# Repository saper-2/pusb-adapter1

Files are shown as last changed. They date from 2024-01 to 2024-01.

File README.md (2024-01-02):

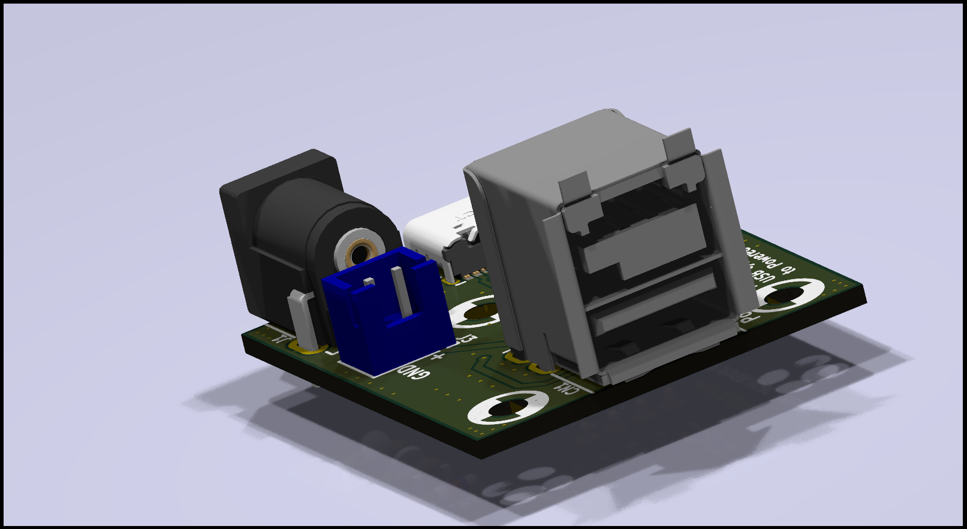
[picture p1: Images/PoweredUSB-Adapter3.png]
Render3D-3

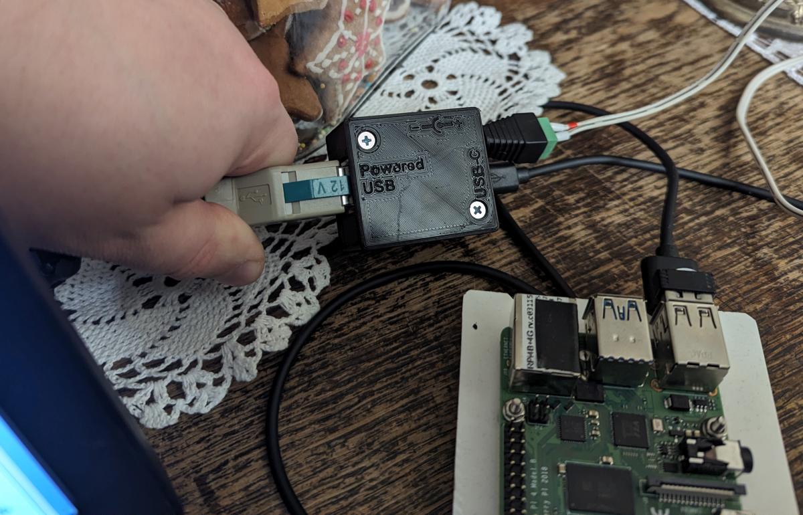
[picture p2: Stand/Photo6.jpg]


# PoweredUSB Adapter board
This repo contains design files for PoweredUSB adapter to USB-C (USB 1.1/2.0 mode) or pinheader with additional power connector (barrel jack socket 5,5x2,1(2,5)mm or JST 2.5mm).

In zip file `PoweredUSB-Adapter-PCB-Fab-Files.zip` are packed gerbers for pcb fab house (this is compressed `out` folder).

In schematic (PDF too) you'll find  part numbers.

In folder `Images` you'll find some 3d renders and pcb dimensions.

## Adapter chassis

In `Chassis` folder you'll find a STLs for adapter box, check readme inside for assembly details.

## Stand
I have designed desk stand for those displays, you can find STL to print on 3D printer (FDM) in `Stand` (and some photos).

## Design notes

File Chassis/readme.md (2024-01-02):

# Chassis for Adapter module

Use 2 nuts M3 + 2 screws M3x25 (DIN 965 / ISO 7046)

Either solder USB-C 16pin connector or solder usb cable to 1x4 goldpin, and cut 2 traces in marked locations (so USB signals won't go back to empty USB-C footprint)

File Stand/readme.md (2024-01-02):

This is v.1.1 stand for Fujitsu 7" LCD Display KD02902-6132 

- Print with support from bed.
- 4 walls, infill 50%

I used PET-G because I had loaded already, but PLA, ABS, other materials will work fine too.

Changelog:
- v1.0 - initial version
- v1.1 - longer front legs, a bit longer central hole so display is about 8-10mm higher, decreased central diameter so lcd will sit more stable (won't be rotating itself).

Stand model also on Thingiverse: https://www.thingiverse.com/thing:6413668

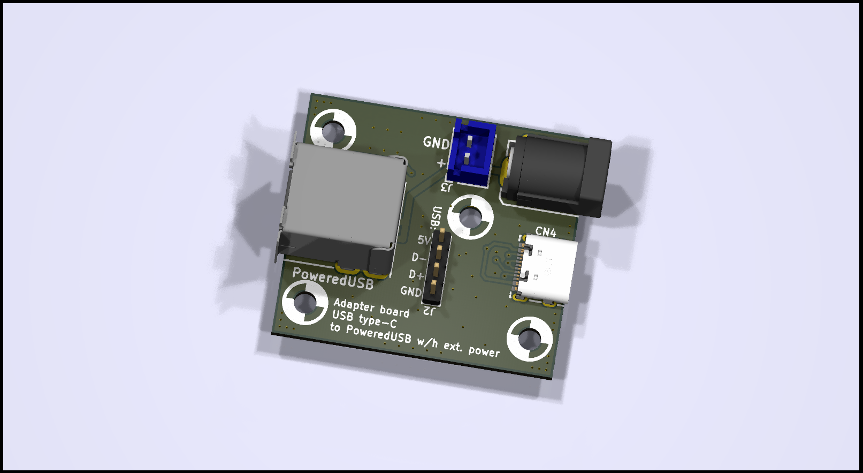
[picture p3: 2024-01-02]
Images/PoweredUSB-Adapter1.png

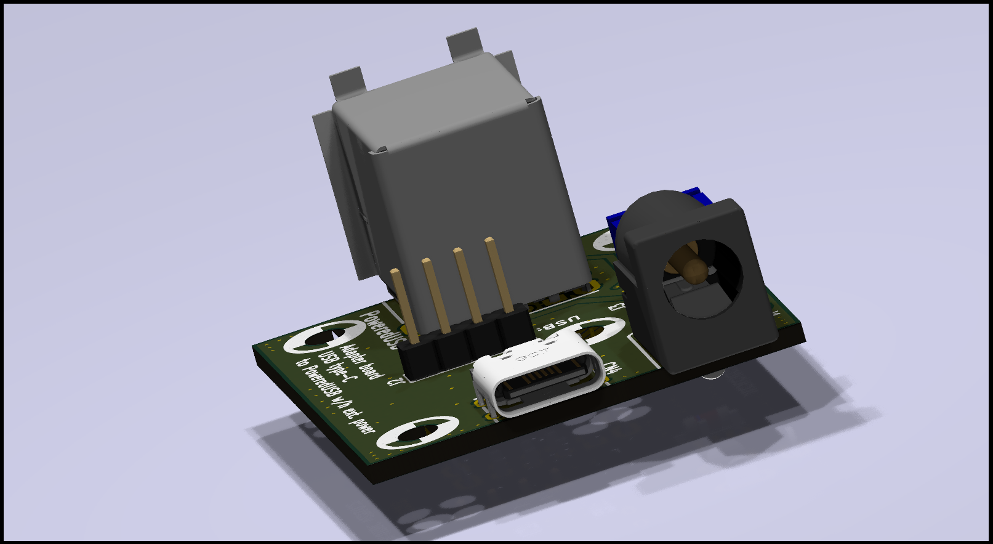
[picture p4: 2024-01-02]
Images/PoweredUSB-Adapter4.png

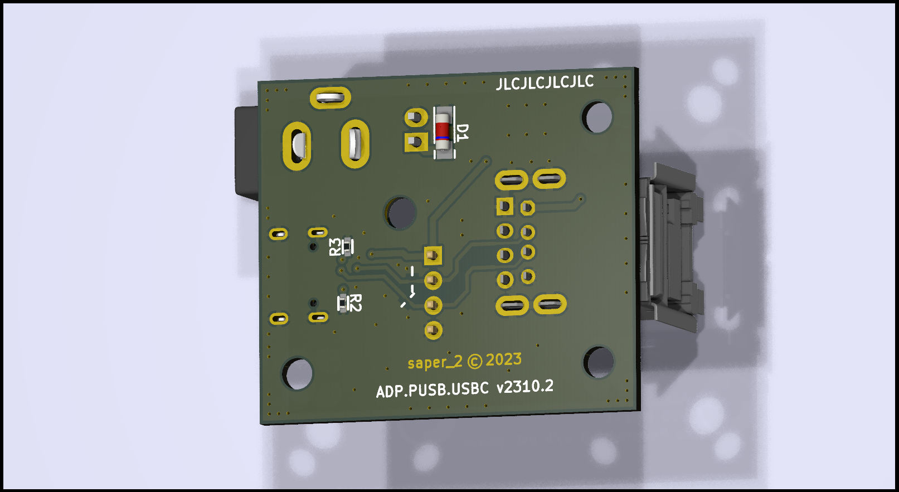
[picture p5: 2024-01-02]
Images/PoweredUSB-Adapter2.png

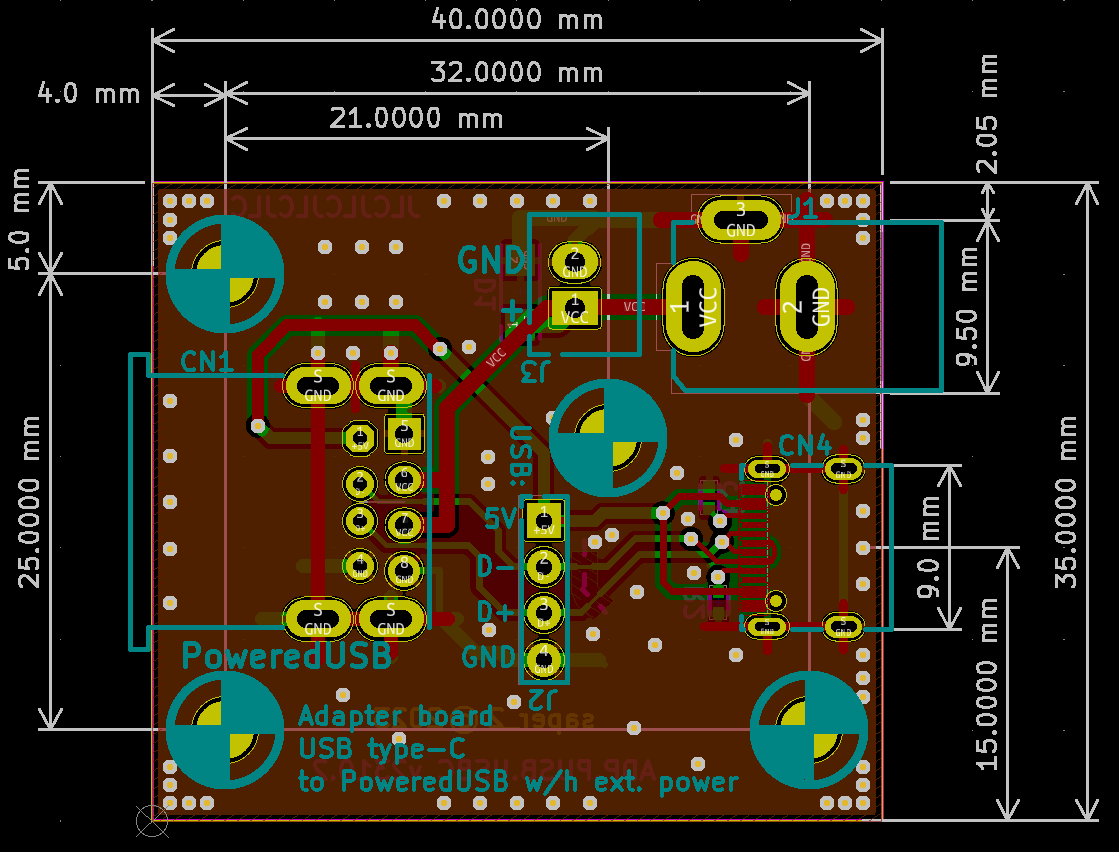
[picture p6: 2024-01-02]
Images/PoweredUSB-Adapter-PCB-Dims.png

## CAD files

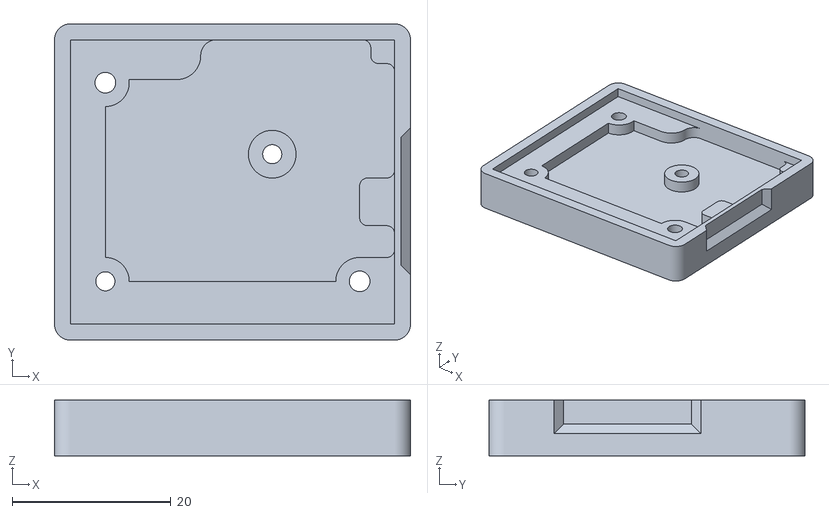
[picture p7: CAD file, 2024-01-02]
Chassis/PoweredUSB-Chassis-Bot(USBC).stl
44.8 x 39.8 x 7.00

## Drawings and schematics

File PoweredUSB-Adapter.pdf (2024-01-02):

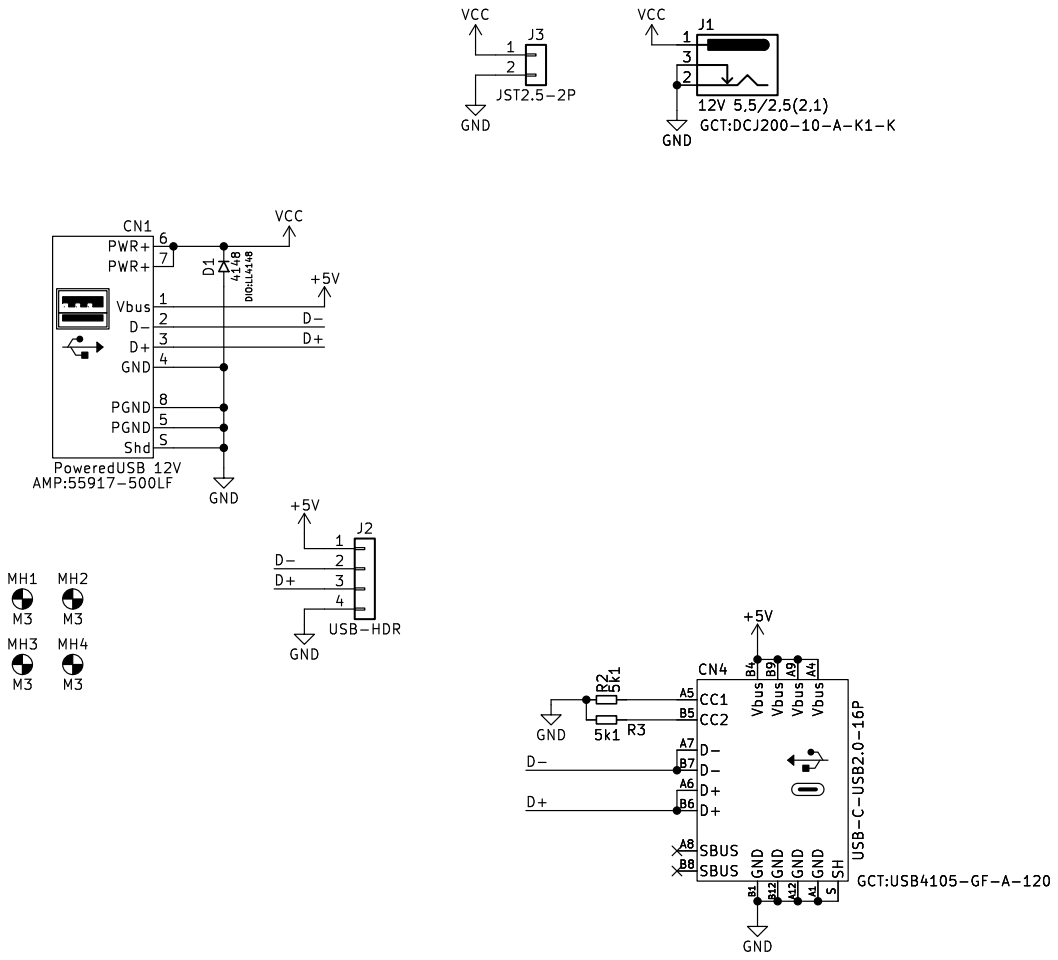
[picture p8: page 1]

S CN4 USB-C-USB2.0-16P GCT:USB4105-GF-A-120 GND

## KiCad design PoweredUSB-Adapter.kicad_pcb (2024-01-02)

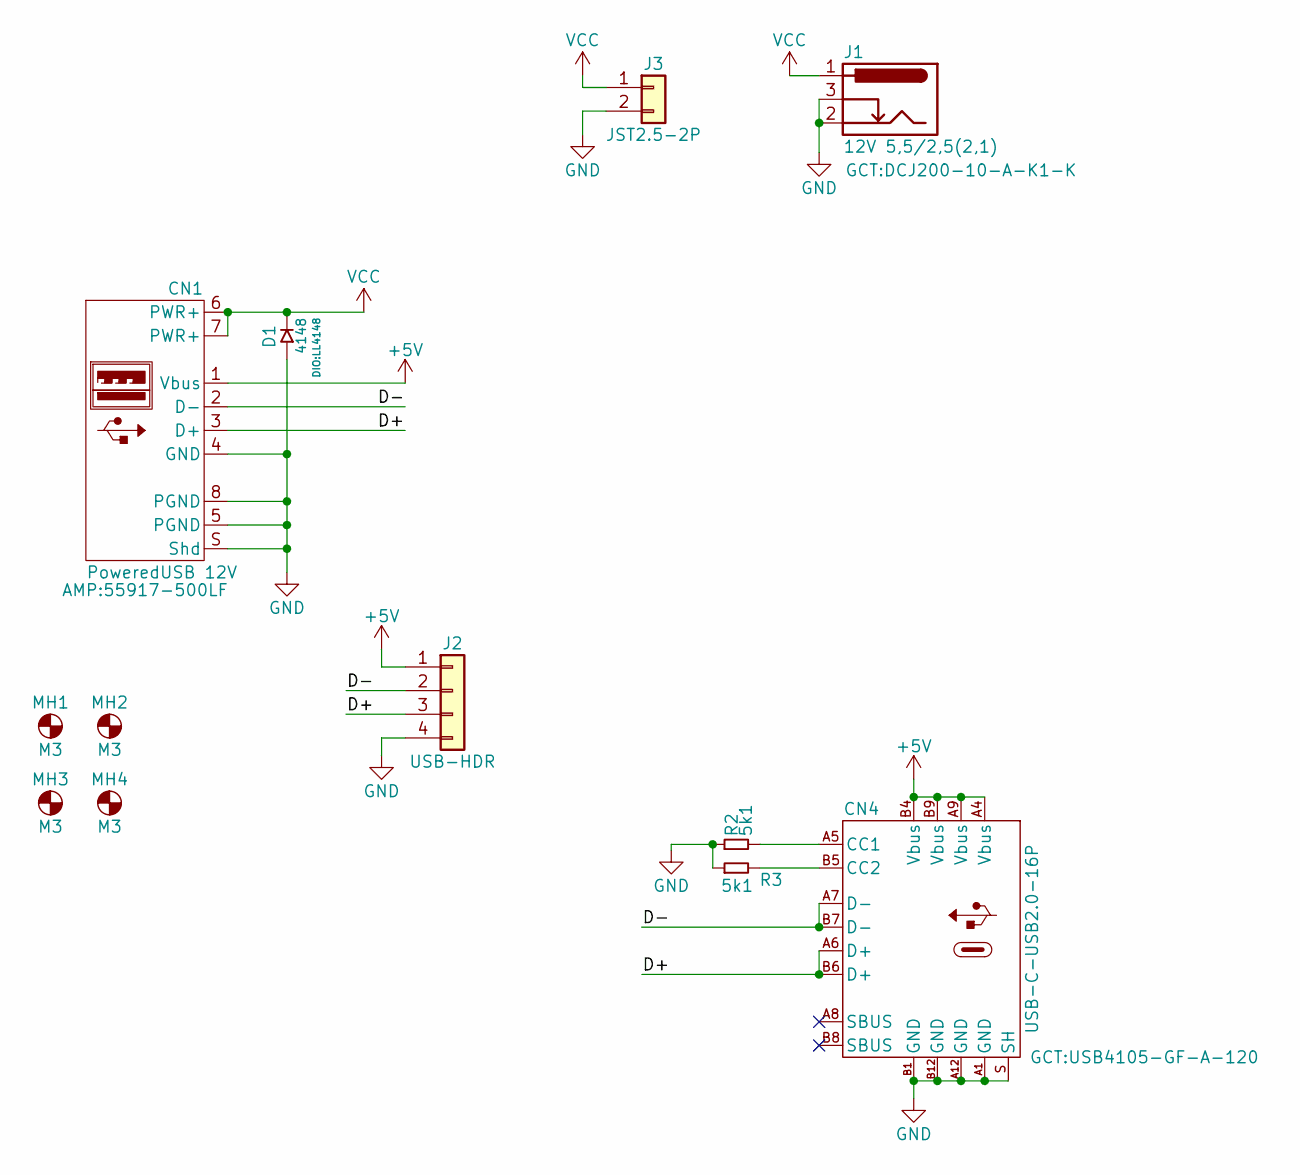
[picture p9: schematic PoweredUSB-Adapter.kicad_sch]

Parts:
CN1: PoweredUSB 12V; AMP_55917-500LF
CN4: USB-C-USB2.0-16P; USBC-F-USB2-16P
D1: 4148; D_MiniMELF_HS
J1: 12V 5,5/2,5(2,1); DC_POWER
J2: USB-HDR; HDR1X04_V
J3: JST2.5-2P; WG04S-2.5-02P-V
MH1, MH2, MH3, MH4: M3; MHOLE-3.2MM
R2, R3: 5k1; R_0402_HS2

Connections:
+5V: CN1.1 (Vbus), CN4.A4 (Vbus), CN4.A9 (Vbus), CN4.B4 (Vbus), CN4.B9 (Vbus), J2.1
/D+: CN1.3 (D+), CN4.A6 (D+), CN4.B6 (D+), J2.3
/D-: CN1.2 (D-), CN4.A7 (D-), CN4.B7 (D-), J2.2
GND: CN1.4 (GND), CN1.5 (PGND), CN1.8 (PGND), CN1.S (Shd), CN4.A1 (GND), CN4.A12 (GND), CN4.B1 (GND), CN4.B12 (GND), CN4.S (SH), D1.2 (A), J1.2, J1.3, J2.4, J3.2, R2.1, R3.1
unnamed: CN4.A5 (CC1), R2.2
unnamed: CN4.B5 (CC2), R3.2
VCC: CN1.6 (PWR+), CN1.7 (PWR+), D1.1 (C), J1.1, J3.1

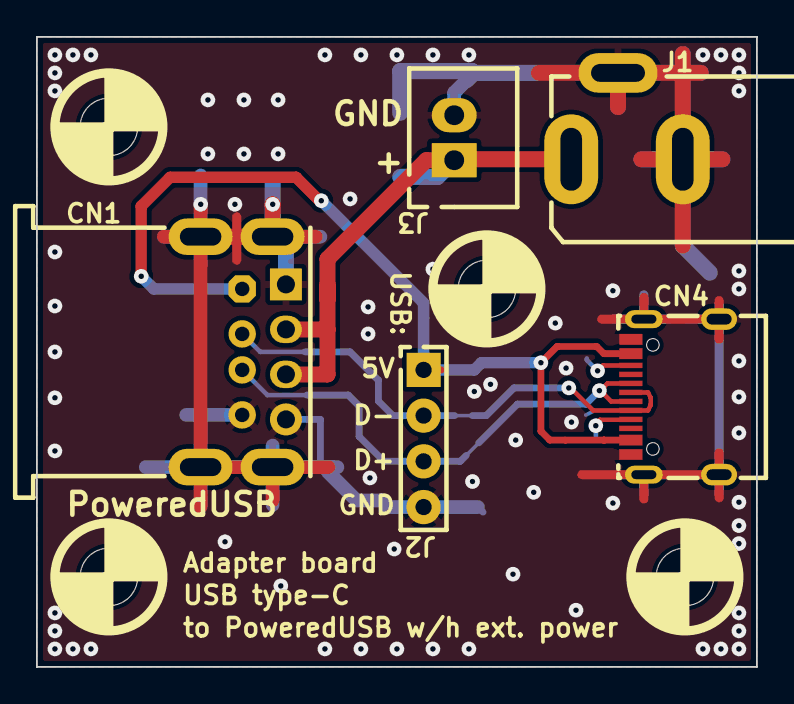
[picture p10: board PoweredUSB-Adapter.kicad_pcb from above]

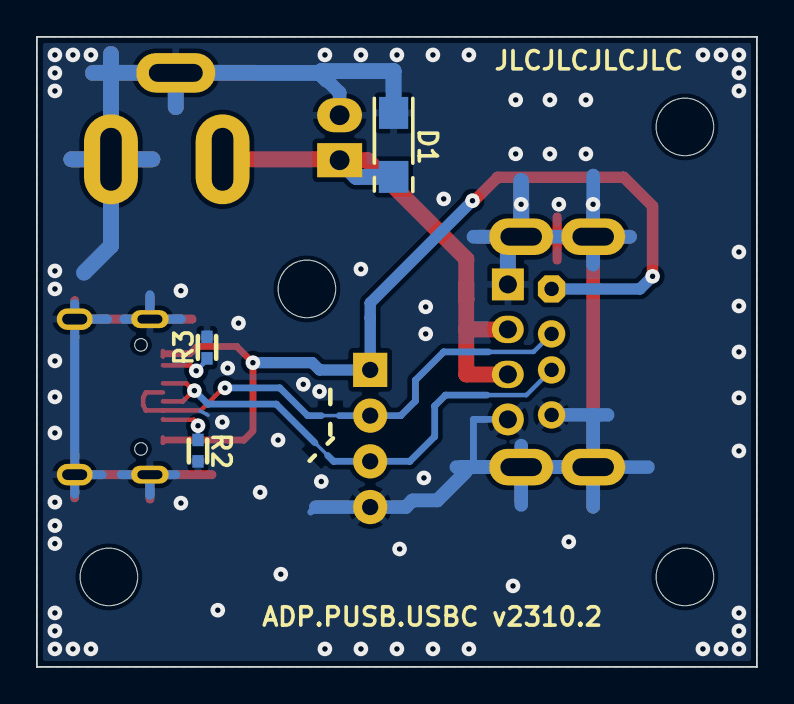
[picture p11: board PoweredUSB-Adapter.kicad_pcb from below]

Board: 2 copper layers, 40.0 x 35.0 mm, 12 parts (3 on the bottom side), 7 nets.
